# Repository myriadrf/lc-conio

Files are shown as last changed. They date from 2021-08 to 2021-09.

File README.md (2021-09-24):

# LibreCellular Remote Console and Power/Reset Control Boards

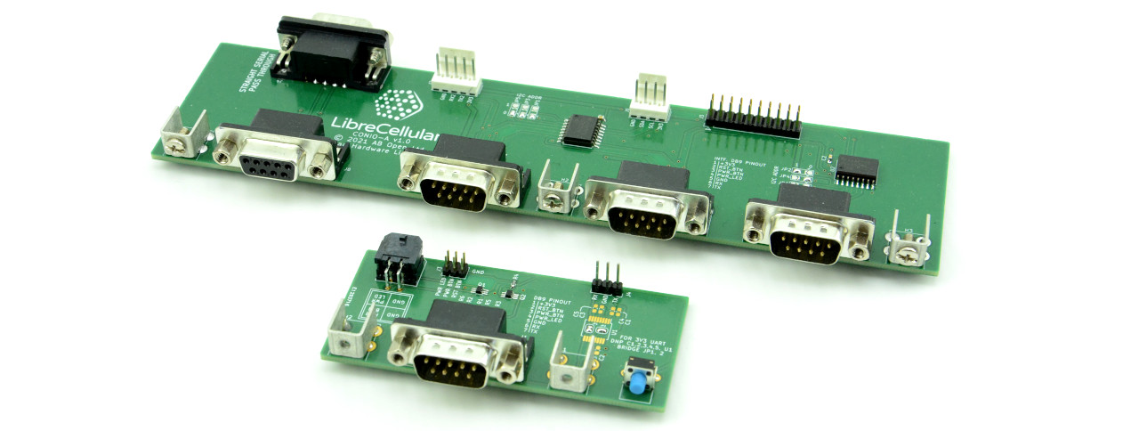
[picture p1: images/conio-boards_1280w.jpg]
LimeRFE board


The CONIO boards provide remote console and power/reset control for SDR base
stations in the [LibreCellular CI hardware platform][1]. 

* **CONIO-A.** Controller (A) end.
* **CONIO-B.** Base station (B) end.

## Contents

The directory structure is as follows:

      /hardware/
          <board>/
              BOM/                   - Bill of materials
              Gerbers/               - Manufacturing files
              KiCAD/                 - KiCAD schematic and layout files
              Mechanical/            - STEP files
              PDF/                   - Schematic and layout PDFs

## Licence

LibreCellular CONIO is copyright 2021 AB Open Ltd and published under the
[Solderpad Hardware License v2.1][2]. 

[1]: https://librecellular.org/developer/ci_hardware.html
[2]: https://solderpad.org/licenses/SHL-2.1/

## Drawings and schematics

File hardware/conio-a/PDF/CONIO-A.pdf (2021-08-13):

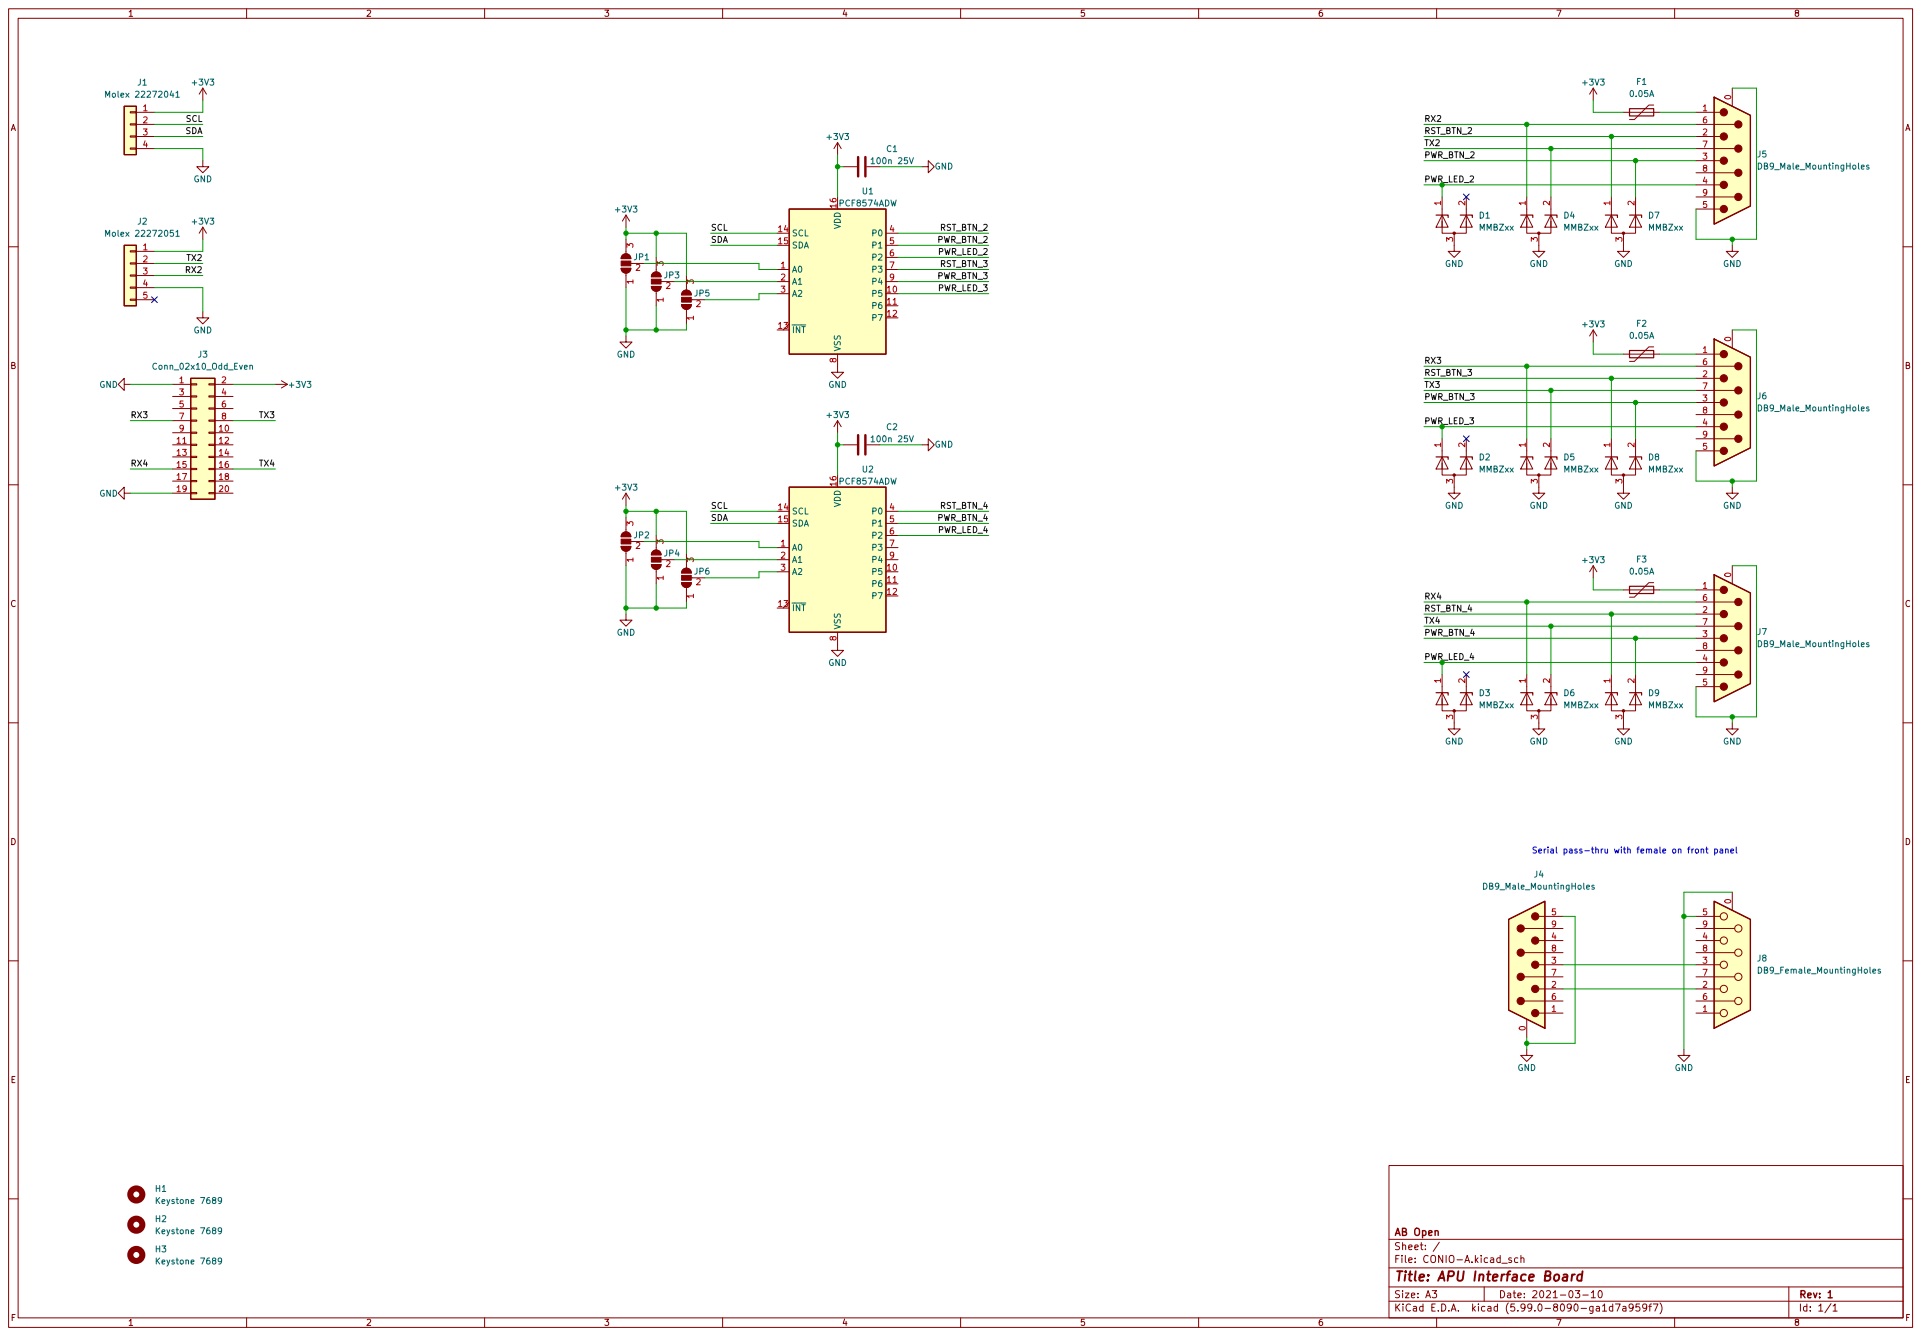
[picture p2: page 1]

Serial pass-thru with female on front panel

File: CONIO-A.kicad_sch Sheet: / AB Open

Id: 1/1 Title: APU Interface Board

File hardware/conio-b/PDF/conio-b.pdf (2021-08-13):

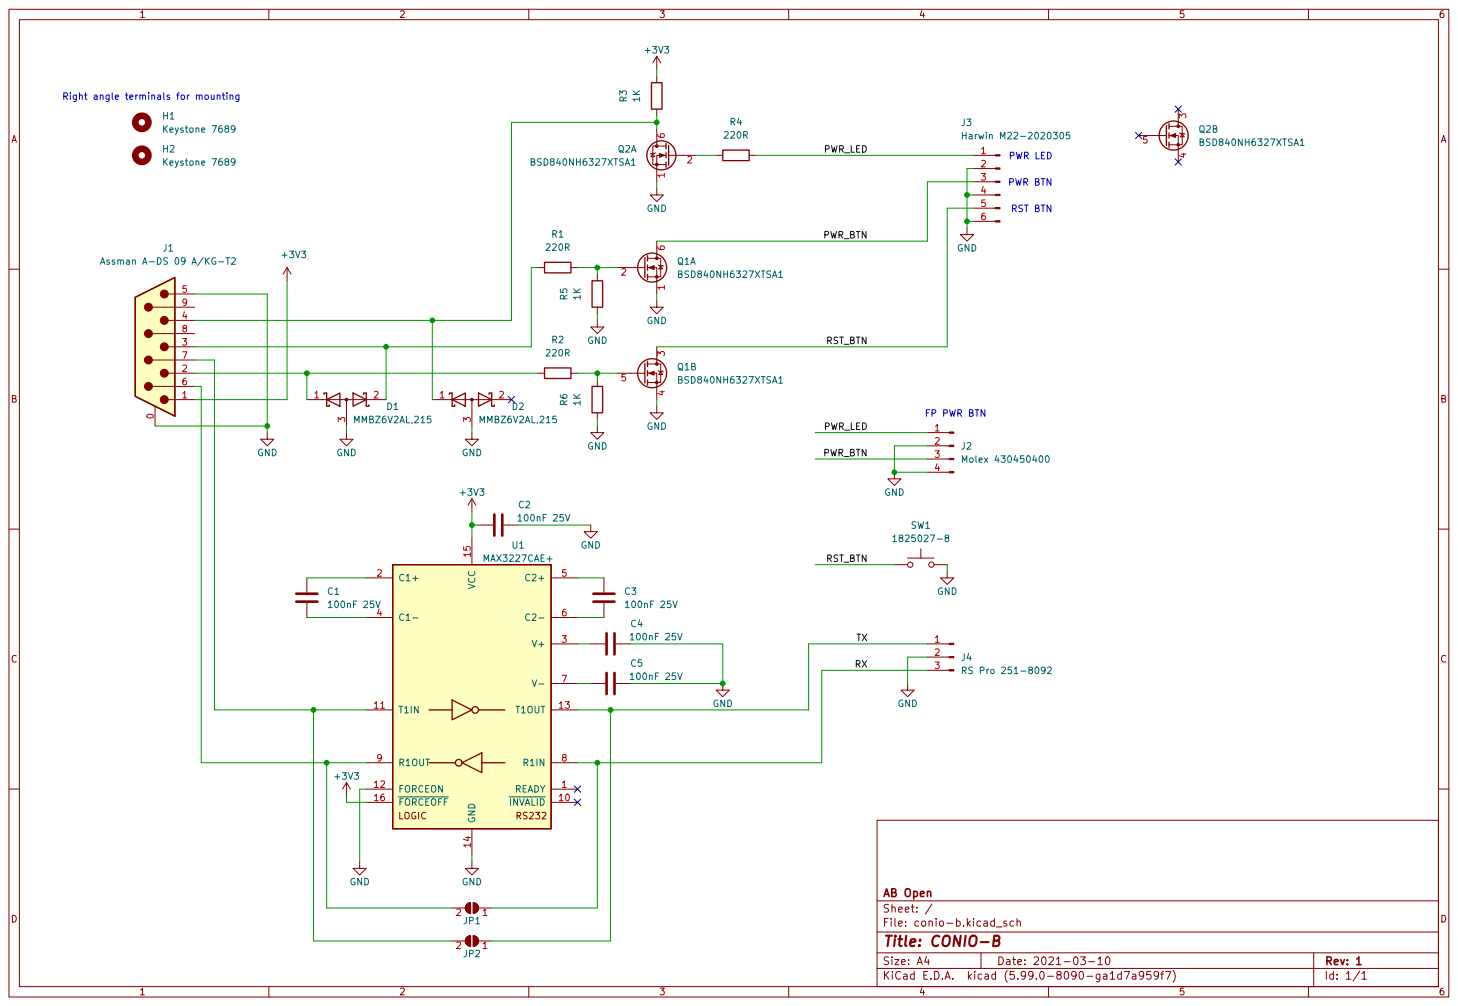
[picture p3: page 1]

3 D1 MMBZ6V2AL,215 GND R6 1K GND GND GND

File: conio-b.kicad_sch Sheet: / AB Open

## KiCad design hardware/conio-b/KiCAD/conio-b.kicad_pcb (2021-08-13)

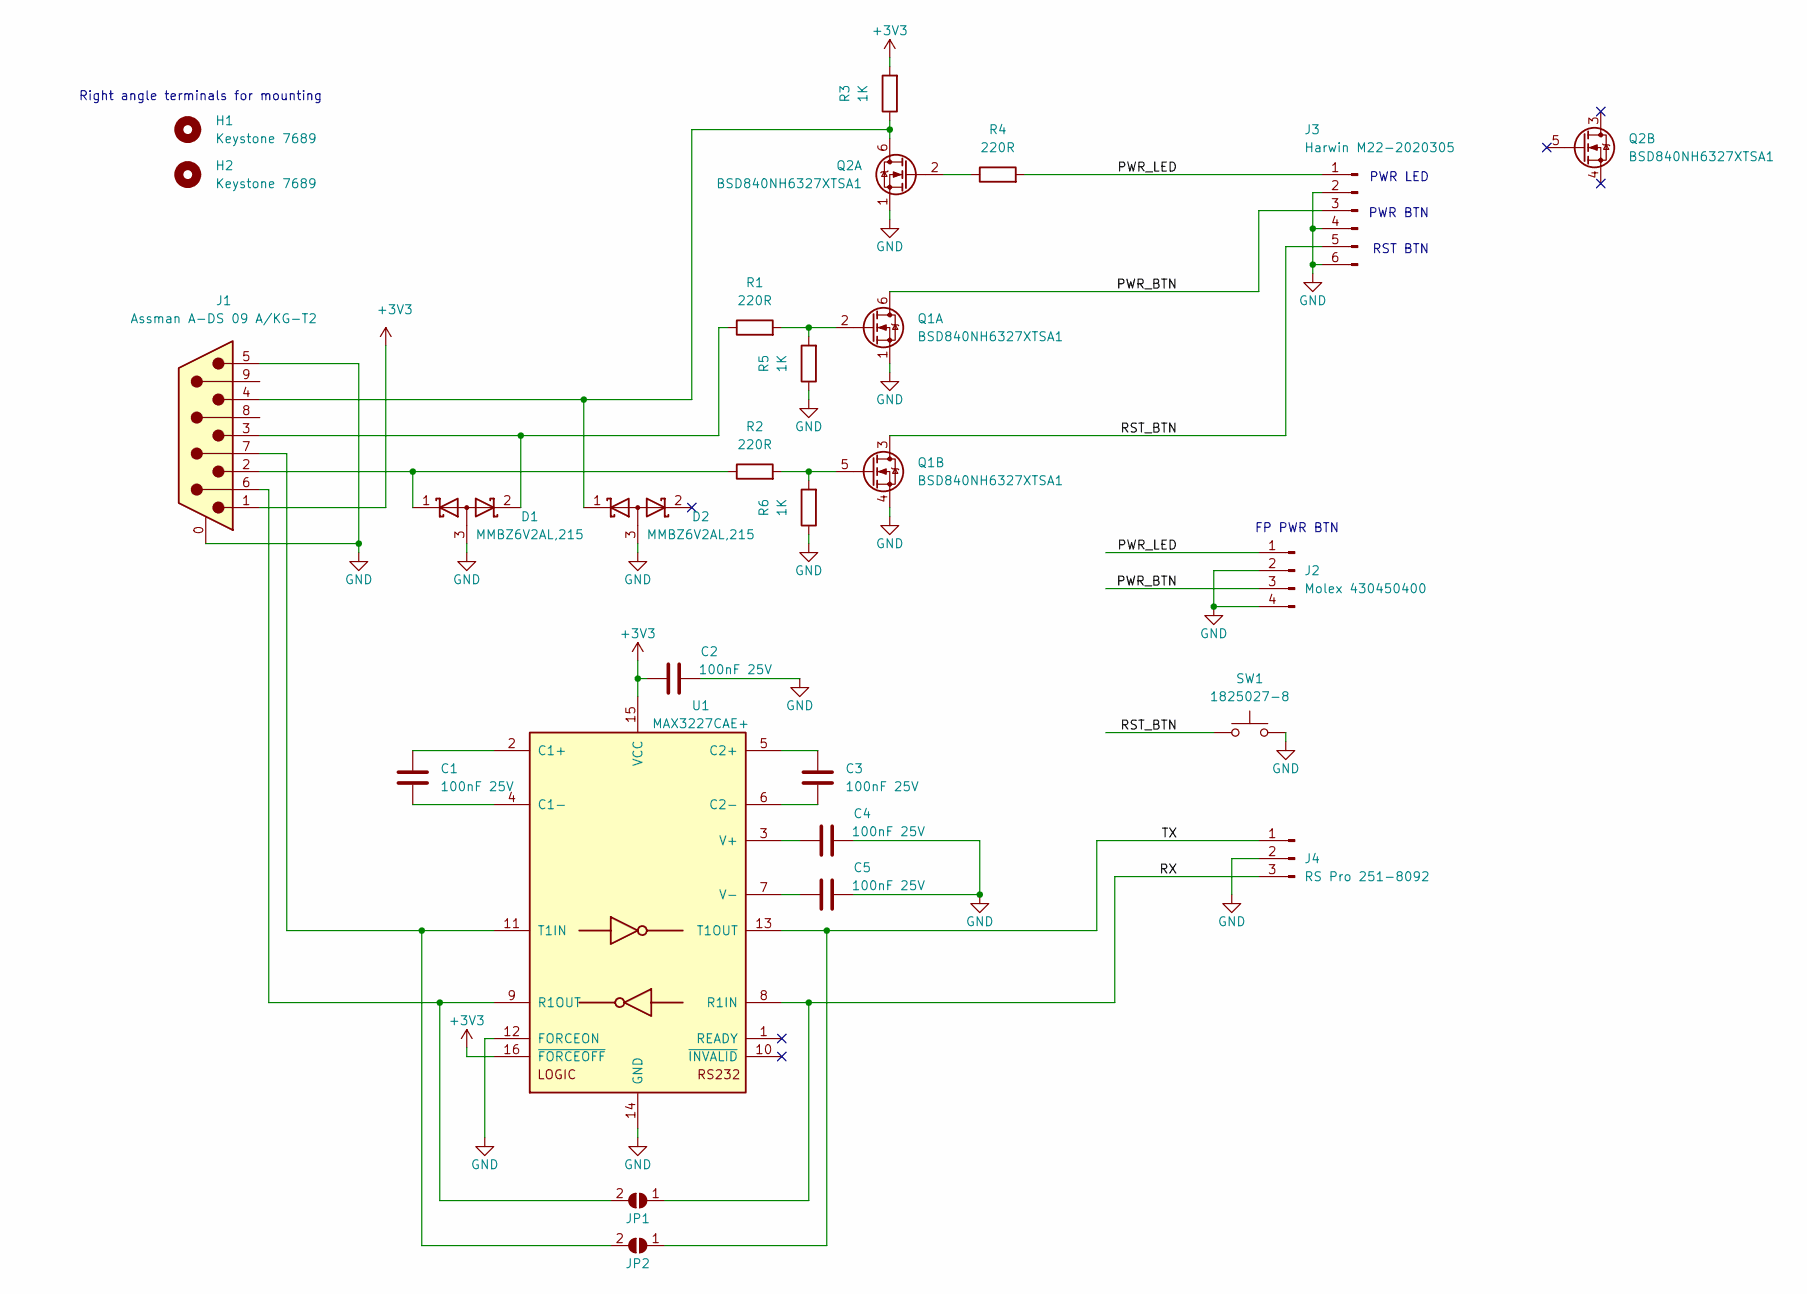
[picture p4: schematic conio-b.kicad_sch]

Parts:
C1, C2, C3, C4, C5: 100nF 25V; C_0603_1608Metric_Pad1.08x0.95mm_HandSolder; ManufacturerPN 06033C104KAZ2A
D1, D2: MMBZ6V2AL,215; SOT-23; ManufacturerPN MMBZ6V2AL,215
H1, H2: Keystone 7689; Keystone_7689_RA_PCB_Screw_Terminal; ManufacturerPN 7689
J1: Assman A-DS 09 A/KG-T2; Assman_A-DS_09_AKG-T2_Male_RA_TH_DB9; ManufacturerPN A-DS 09 A/KG-T2
J2: Molex 430450400; Molex_Micro-Fit_3.0_43045-0400_2x02_P3.00mm_Horizontal; ManufacturerPN 430450400
J3: Harwin M22-2020305; PinHeader_2x03_P2.00mm_Vertical; ManufacturerPN M22-2020305
J4: RS Pro 251-8092; PinSocket_1x03_P2.54mm_Vertical; ManufacturerPN 251-8092
JP1, JP2: SolderJumper_2_Open; SolderJumper-2_P1.3mm_Open_RoundedPad1.0x1.5mm
Q1, Q2: BSD840NH6327XTSA1; SOT-363_SC-70-6_Handsoldering; ManufacturerPN BSD840NH6327XTSA1
R1, R2, R4: 220R; R_0603_1608Metric_Pad0.98x0.95mm_HandSolder; ManufacturerPartNumber RC0603FR-07220RL
R3, R5, R6: 1K; R_0603_1608Metric_Pad0.98x0.95mm_HandSolder; ManufacturerPN RC0603FR-071KL
SW1: 1825027-8; TE_Connectivity_1825027-8_FSMRA3JH_Pushbutton; ManufacturerPN 1825027-8
U1: MAX3227CAE+; SSOP-16_5.3x6.2mm_P0.65mm; ManufacturerPN MAX3227CAE+

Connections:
+3V3: C2.1, J1.1, R3.2, U1.15 (VCC), U1.16 (~FORCEOFF)
/PWR_BTN: J2.3, J3.3, Q1.6 (D)
/PWR_LED: J2.1, J3.1, R4.2
/RST_BTN: J3.5, Q1.3 (D), SW1.1
/RX: J4.3, JP1.1 (A), U1.8 (R1IN)
/TX: J4.1, JP2.1 (A), U1.13 (T1OUT)
GND: C2.2, C4.2, C5.2, D1.3 (A), D2.3 (A), J1.0 (PAD), J1.5, J2.2, J2.4, J3.2, J3.4, J3.6, J4.2, Q1.1 (S), Q1.4 (S), Q2.1 (S), R5.1, R6.1, SW1.2, U1.12 (FORCEON), U1.14 (GND)
unnamed: C1.1, U1.2 (C1+)
unnamed: C1.2, U1.4 (C1-)
unnamed: C3.1, U1.5 (C2+)
unnamed: C3.2, U1.6 (C2-)
unnamed: C4.1, U1.3 (V+)
unnamed: C5.1, U1.7 (V-)
unnamed: D1.1 (K), J1.2, R2.1
unnamed: D1.2 (K), J1.3, R1.1
unnamed: D2.1 (K), J1.4, Q2.6 (D), R3.1
unnamed: J1.6, JP1.2 (B), U1.9 (R1OUT)
unnamed: J1.7, JP2.2 (B), U1.11 (T1IN)
unnamed: Q1.2 (G), R1.2, R5.2
unnamed: Q1.5 (G), R2.2, R6.2
unnamed: Q2.2 (G), R4.1
no_connect_24: D2.2 (K)
no_connect_25: Q2.3 (D)
no_connect_26: Q2.4 (S)
no_connect_27: Q2.5 (G)
no_connect_28: U1.1 (READY)
no_connect_29: U1.10 (~INVALID)

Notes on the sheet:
Right angle terminals for mounting
FP PWR BTN
PWR LED
PWR BTN
RST BTN

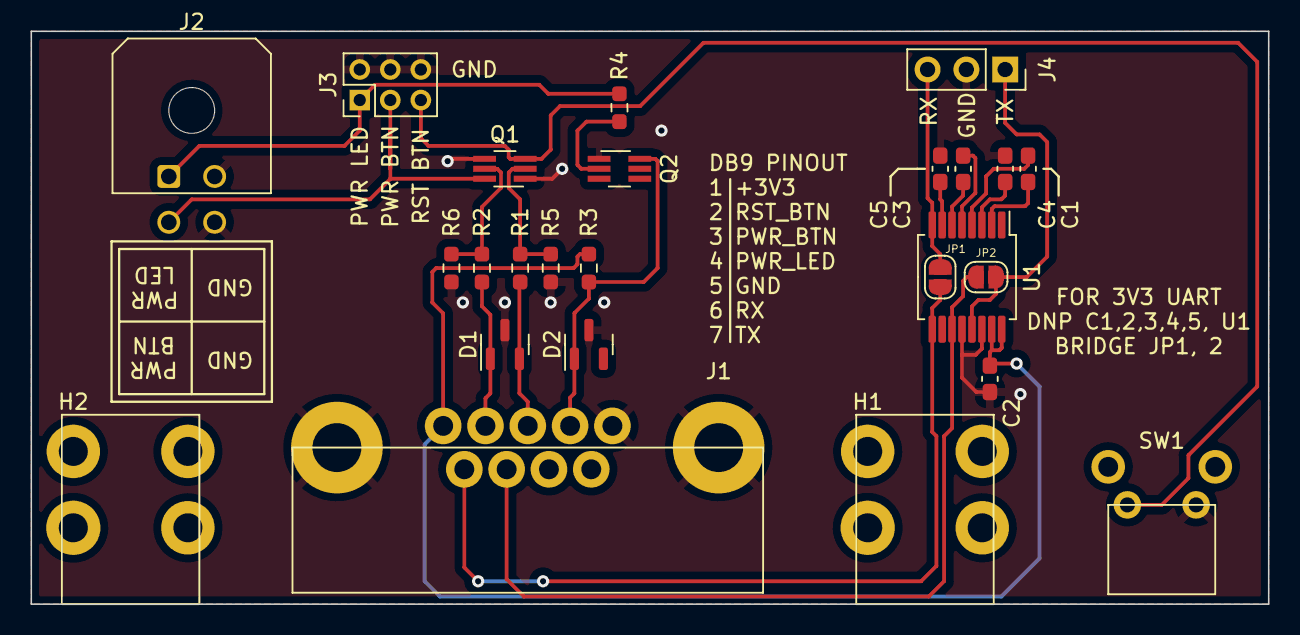
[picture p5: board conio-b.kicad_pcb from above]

Board: 2 copper layers, 81.0 x 37.5 mm, 25 parts (0 on the bottom side), 21 nets.

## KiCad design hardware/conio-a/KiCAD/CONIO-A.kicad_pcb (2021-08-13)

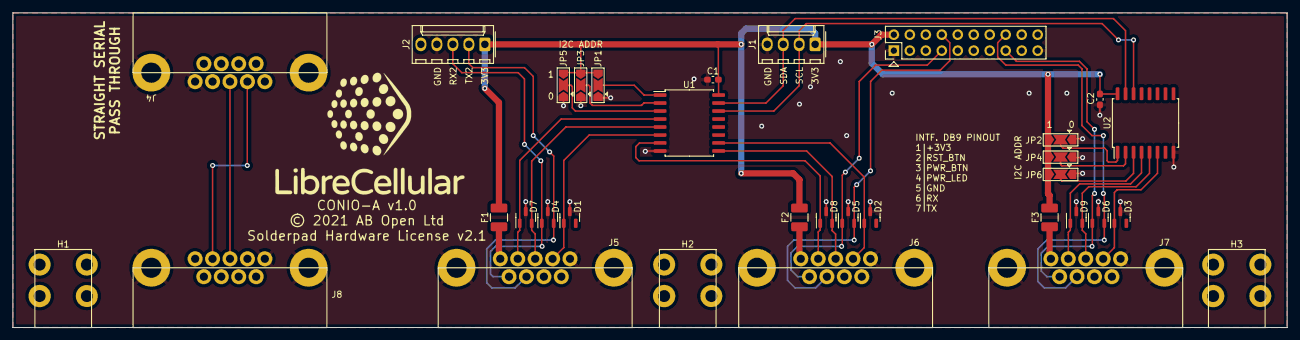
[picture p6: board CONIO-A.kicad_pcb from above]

Board: 2 copper layers, 202.5 x 50.0 mm, 34 parts (0 on the bottom side), 30 nets.

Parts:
C1, C2: 100n 25V; C_0603_1608Metric_Pad1.08x0.95mm_HandSolder
D1, D2, D3, D4, D5, D6, D7, D8, D9: MMBZxx; SOT-23
F1, F2, F3: 0.05A; Fuse_1210_3225Metric_Pad1.42x2.65mm_HandSolder
H1, H2, H3: Keystone 7689; Keystone_7689_RA_PCB_Screw_Terminal
J1: Molex 22272041; Molex_KK-254_AE-6410-04A_1x04_P2.54mm_Vertical
J2: Molex 22272051; Molex_KK-254_AE-6410-05A_1x05_P2.54mm_Vertical
J3: Conn_02x10_Odd_Even; PinSocket_2x10_P2.54mm_Vertical_Flipped
J4, J5, J6, J7: DB9_Male_MountingHoles; Assman_A-DS_09_AKG-T2_Male_RA_TH_DB9
J8: DB9_Female_MountingHoles; Assman_A-DS_09_AKG-T2_Male_RA_TH_DB9
JP1, JP2, JP3, JP4, JP5, JP6: SolderJumper_3_Open; SolderJumper-3_P2.0mm_Open_TrianglePad1.0x1.5mm
Ref**: Val**; LibreCellular_Logo
U1, U2: PCF8574ADW; SOIC-16W_7.5x10.3mm_P1.27mm

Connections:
+3V3: C1.1, C2.1, F1.1, F2.1, F3.1, J1.1, J2.1, J3.2, JP1.3 (B), JP2.3 (B), JP3.3 (B), JP4.3 (B), JP5.3 (B), JP6.3 (B), U1.16 (VDD), U2.16 (VDD)
/PWR_BTN_2: D7.2 (K), J5.3, U1.5 (P1)
/PWR_BTN_3: D8.2 (K), J6.3, U1.9 (P4)
/PWR_BTN_4: D9.2 (K), J7.3, U2.5 (P1)
/PWR_LED_2: D1.1 (K), J5.4, U1.6 (P2)
/PWR_LED_3: D2.1 (K), J6.4, U1.10 (P5)
/PWR_LED_4: D3.1 (K), J7.4, U2.6 (P2)
/RST_BTN_2: D7.1 (K), J5.2, U1.4 (P0)
/RST_BTN_3: D8.1 (K), J6.2, U1.7 (P3)
/RST_BTN_4: D9.1 (K), J7.2, U2.4 (P0)
/RX2: D4.1 (K), J2.3, J5.6
/RX3: D5.1 (K), J3.7, J6.6
/RX4: D6.1 (K), J3.15, J7.6
/SCL: J1.2, U1.14 (SCL), U2.14 (SCL)
/SDA: J1.3, U1.15 (SDA), U2.15 (SDA)
/TX2: D4.2 (K), J2.2, J5.7
/TX3: D5.2 (K), J3.8, J6.7
/TX4: D6.2 (K), J3.16, J7.7
GND: C1.2, C2.2, D1.3 (A), D2.3 (A), D3.3 (A), D4.3 (A), D5.3 (A), D6.3 (A), D7.3 (A), D8.3 (A), D9.3 (A), J1.4, J2.4, J3.1, J3.19, J4.0 (PAD), J4.5, J5.0 (PAD), J5.5, J6.0 (PAD), J6.5, J7.0 (PAD), J7.5, J8.0 (PAD), J8.5, JP1.1 (A), JP2.1 (A), JP3.1 (A), JP4.1 (A), JP5.1 (A), JP6.1 (A), U1.8 (VSS), U2.8 (VSS)
unnamed: F1.2, J5.1
unnamed: F2.2, J6.1
unnamed: F3.2, J7.1
unnamed: J4.2, J8.2
unnamed: J4.3, J8.3
unnamed: JP1.2 (C), U1.1 (A0)
unnamed: JP2.2 (C), U2.1 (A0)
unnamed: JP3.2 (C), U1.2 (A1)
unnamed: JP4.2 (C), U2.2 (A1)
unnamed: JP5.2 (C), U1.3 (A2)
unnamed: JP6.2 (C), U2.3 (A2)

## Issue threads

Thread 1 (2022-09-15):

Fix CONIO-A DB9 pinout

callumsnowden, 2022-09-15:
Console DB9 pinout is incorrect with wrong pins due to footprints being incorrect. Amend, or additionally replace front panel connector with a FTDI USB-RS232 module.

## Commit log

2021-08-13 Initial project commit
    - Added LICENSE file
    - Added CONIO-A and CONIO-B projects, organised into appropriate directory structure
    [CONIO-A-B_Cu.gbl, CONIO-A-B_Mask.gbs, CONIO-A-B_Silkscreen.gbo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]
2021-09-24 Minor reorg, add photo and update README.
    [CONIO-A-B_Cu.gbl, CONIO-A-B_Mask.gbs, CONIO-A-B_Silkscreen.gbo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]

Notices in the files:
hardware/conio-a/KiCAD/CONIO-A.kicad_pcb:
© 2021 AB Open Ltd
